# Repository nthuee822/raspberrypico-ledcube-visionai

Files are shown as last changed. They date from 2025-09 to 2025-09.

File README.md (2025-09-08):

# raspberrypico-ledcube-visionai
An application of a Raspberry Pi Pico–based 8x8x8 LED cube with Grove Vision AI v2 module

## Introduction

There are many tutorials online about how to build an 8x8x8 LED Cube, but very few showcase practical applications. During an exhibition, we came across the Grove Vision AI V2 module, which inspired us to combine the two into a unique project.

Here’s how our system works: the camera on the Grove Vision AI V2 first recognizes a hand gesture (rock, paper, or scissors). It then sends the result via I²C to the Raspberry Pi Pico 2. The Pico 2 processes the data and communicates with the LED Cube’s PCB through the SPI interface. The PCB, equipped with eight shift registers, controls the LED Cube’s X–Y plane, while an additional perfboard manages the Z-axis. We will present the hardware setup in the next section.

This project is significant for two main reasons. First, we developed a library for the Grove Vision AI V2 to transmit data to Raspberry Pi Pico , making it easier for developers to integrate and leverage its vision features. Second, we created a generalized Raspberry Pi Pico library for the 8x8x8 LED Cube, allowing developers to easily modify display patterns simply by adjusting the code.

## Getting Started

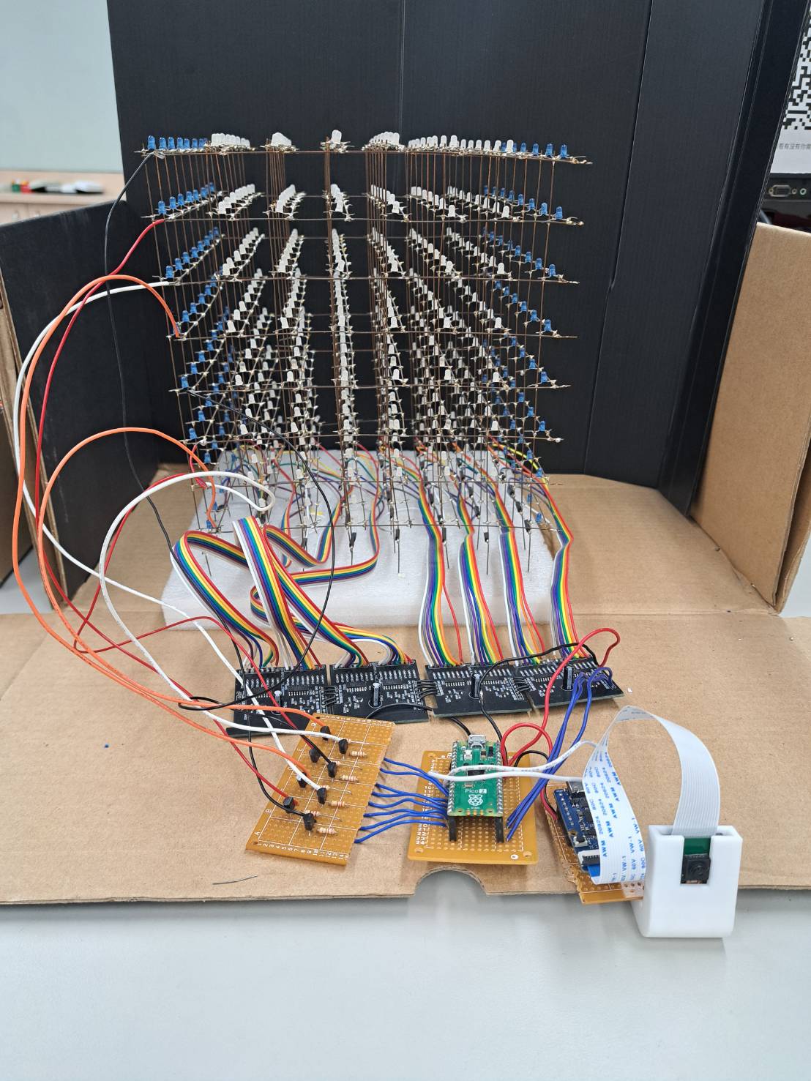
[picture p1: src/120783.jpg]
<p align="center"> <br> figure 1. </p>

### Hardware setup: Grove vision AI v2 module

We recommend using the more powerful Grove Vision AI V2 for this project. Setup instructions can be found at the official guide: https://wiki.seeedstudio.com/grove_vision_ai_v2/.

The connection between the Grove Vision AI V2, Raspberry Pi Pico 2, and the PCB with eight shift registers is shown in figure 2.

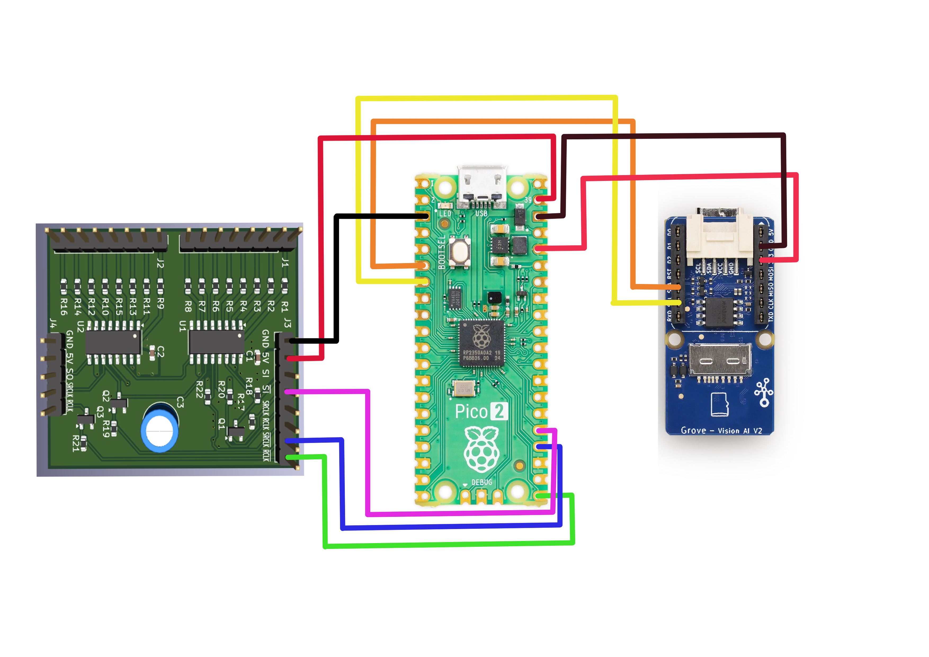
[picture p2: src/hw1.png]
<p align="center"> <br> figure 2. </p>

### Hardware setup: 8x8x8 LED Cube

The four PCBs, each with eight shift registers, are connected as shown in figure 3.

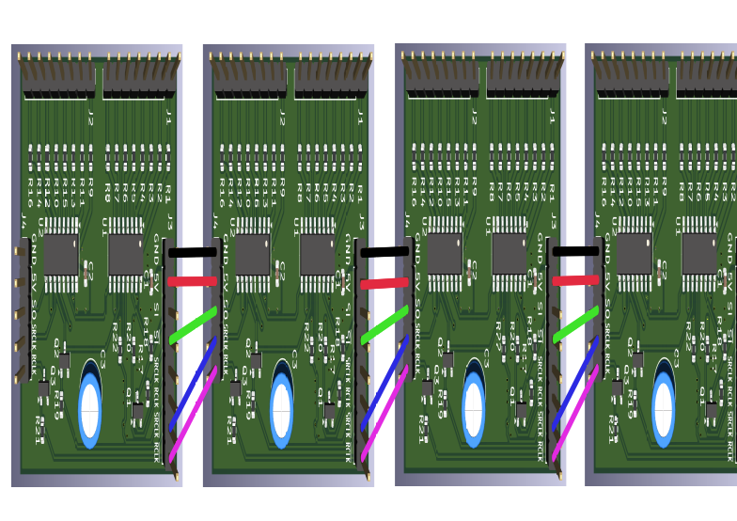
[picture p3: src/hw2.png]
<p align="center"> <br> figure 3. </p>

The perfboard manages the Z-axis. Pins 6 to 13 on the Raspberry Pi Pico 2 are connected to eight 220 Ω resistors and eight NPN transistors, as shown in figure 4.

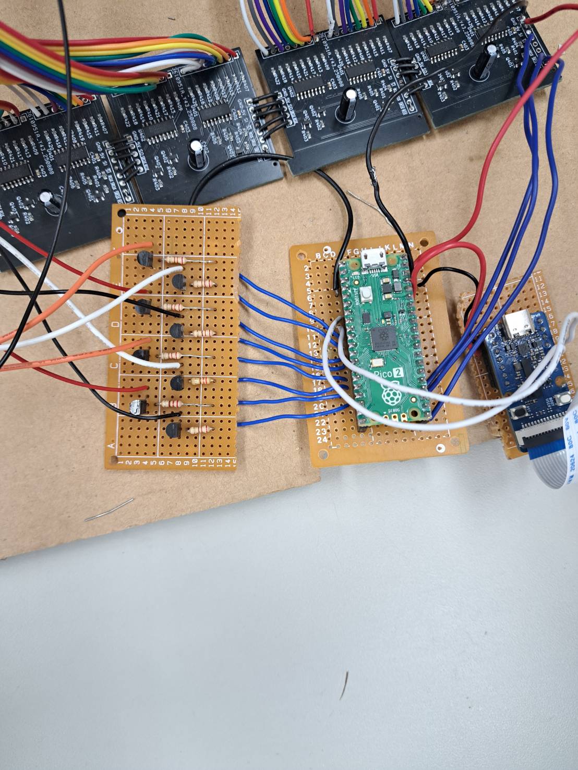
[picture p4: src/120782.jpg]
<p align="center"> <br> figure 4. </p>

## Software

### Grove vision AI v2 module

We revised the official Seeed_Arduino_SSCMA library (originally for Arduino) into an I²C interface library for the Raspberry Pi Pico.
This makes it easier to integrate the Grove Vision AI V2 with Pico-based projects.

### 8x8x8 LED Cube
We provide two versions of code for the LED Cube:

#### led_cube.c
A standalone project with several predefined special effects.
Simply run the code on the Raspberry Pi Pico, and it will light up the 8x8x8 LED Cube with built-in animations.

#### Cube_general.c
A more generalized implementation.
Developers can easily customize display effects by modifying only the matrix definition.

### Combination
Finally, we integrated everything into a rock–paper–scissors gesture recognition system.
The Grove Vision AI V2 recognizes the gesture, and the result is projected onto the 8x8x8 LED Cube.

For further details, please refer to Cube.cpp.

## Equipment Used

- [Raspberry Pi Pico](https://www.raspberrypi.com/products/raspberry-pi-pico/)
- [Grove Vision AI V2](https://wiki.seeedstudio.com/grove_vision_ai_v2/)
- [Seeed-Arduino_SSCMA Library](https://github.com/Seeed-Studio/Seeed_Arduino_SSCMA/)

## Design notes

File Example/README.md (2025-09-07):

We also created several special effects for the LED Cube in the file led_cube.c.
This version is a standalone project that does not use the AI Vision module.
Simply run the code on the Raspberry Pi Pico, and it will light up the 8x8x8 LED Cube with predefined animations.

For developers who prefer more flexibility, we provide Cube_general.c, which offers a generalized implementation.
With this code, display effects can be easily modified by changing only the matrix definition.

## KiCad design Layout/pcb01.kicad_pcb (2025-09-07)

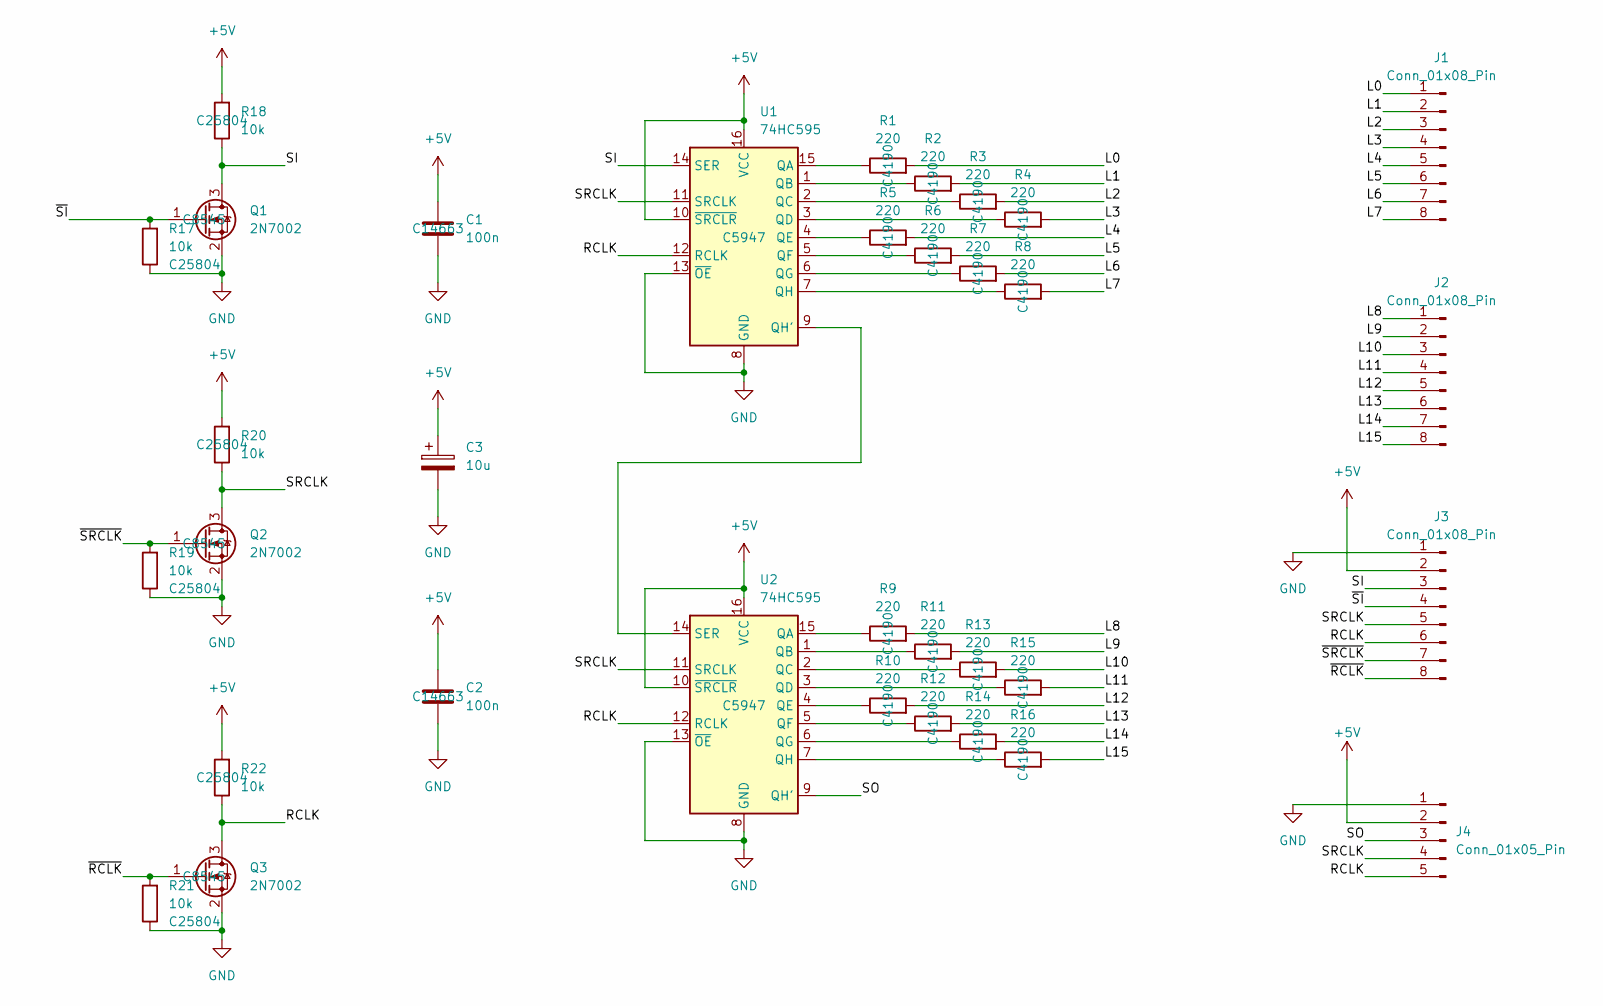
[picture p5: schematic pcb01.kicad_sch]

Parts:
C1, C2: 100n; C_0603_1608Metric; LCSC C14663
C3: 10u; C_Radial_D6.3mm_H7.0mm_P2.50mm
J1, J2, J3: Conn_01x08_Pin; PinHeader_1x08_P2.54mm_Vertical
J4: Conn_01x05_Pin; PinHeader_1x05_P2.54mm_Vertical
Q1, Q2, Q3: 2N7002; SOT-23; LCSC C8545
R1, R2, R3, R4, R5, R6, R7, R8, R9, R10, R11, R12, R13, R14, R15, R16: 220; R_0603_1608Metric; LCSC C4190
R17, R18, R19, R20, R21, R22: 10k; R_0603_1608Metric; LCSC C25804
U1, U2: 74HC595; SOIC-16_3.9x9.9mm_P1.27mm; LCSC C5947

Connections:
+5V: C1.1, C2.1, C3.1, J3.2, J4.2, R18.2, R20.2, R22.2, U1.10 (~SRCLR), U1.16 (VCC), U2.10 (~SRCLR), U2.16 (VCC)
/L0: J1.1, R1.2
/L1: J1.2, R2.2
/L2: J1.3, R3.2
/L3: J1.4, R4.2
/L4: J1.5, R5.2
/L5: J1.6, R6.2
/L6: J1.7, R7.2
/L7: J1.8, R8.2
/L8: J2.1, R9.2
/L9: J2.2, R11.2
/L10: J2.3, R13.2
/L11: J2.4, R15.2
/L12: J2.5, R10.2
/L13: J2.6, R12.2
/L14: J2.7, R14.2
/L15: J2.8, R16.2
/RCLK: J3.6, J4.5, Q3.3 (D), R22.1, U1.12 (RCLK), U2.12 (RCLK)
/SI: J3.3, Q1.3 (D), R18.1, U1.14 (SER)
/SO: J4.3, U2.9 (QH')
/SRCLK: J3.5, J4.4, Q2.3 (D), R20.1, U1.11 (SRCLK), U2.11 (SRCLK)
/~RCLK: J3.8, Q3.1 (G), R21.2
/~SI: J3.4, Q1.1 (G), R17.2
/~SRCLK: J3.7, Q2.1 (G), R19.2
GND: C1.2, C2.2, C3.2, J3.1, J4.1, Q1.2 (S), Q2.2 (S), Q3.2 (S), R17.1, R19.1, R21.1, U1.8 (GND), U1.13 (~OE), U2.8 (GND), U2.13 (~OE)
unnamed: R1.1, U1.15 (QA)
unnamed: R2.1, U1.1 (QB)
unnamed: R3.1, U1.2 (QC)
unnamed: R4.1, U1.3 (QD)
unnamed: R5.1, U1.4 (QE)
unnamed: R6.1, U1.5 (QF)
unnamed: R7.1, U1.6 (QG)
unnamed: U1.9 (QH'), U2.14 (SER)
unnamed: R8.1, U1.7 (QH)
unnamed: R9.1, U2.15 (QA)
unnamed: R11.1, U2.1 (QB)
unnamed: R13.1, U2.2 (QC)
unnamed: R15.1, U2.3 (QD)
unnamed: R10.1, U2.4 (QE)
unnamed: R12.1, U2.5 (QF)
unnamed: R14.1, U2.6 (QG)
unnamed: R16.1, U2.7 (QH)

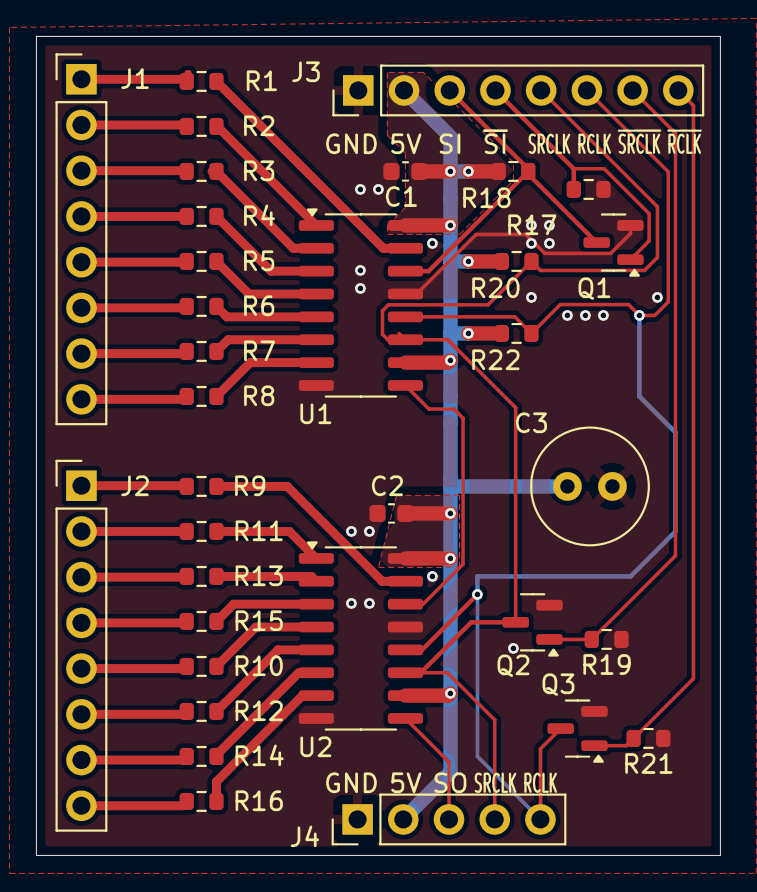
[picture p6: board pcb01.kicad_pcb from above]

Board: 2 copper layers, 38.0 x 45.5 mm, 34 parts (0 on the bottom side), 42 nets.

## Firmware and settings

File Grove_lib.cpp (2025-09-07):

#include "Grove_lib.h"

#define SPI_CS(x)                 \
    do                            \
    {                             \
        if (_cs >= 0)             \
            gpio_put(_cs, x); \
    } while (0)
 
SSCMA::SSCMA()
{
    _i2c = NULL;
    _address = I2C_ADDRESS;
    _wait_delay = 2;
    _rst = -1;
    _cs = -1;
    _sync = -1;
    tx_len = 0;
    rx_len = 0;
}
 
SSCMA::~SSCMA() {}
 
bool SSCMA::begin(i2c_inst_t *i2c, int32_t rst, uint16_t address, uint32_t wait_delay,
                   uint32_t clock)
{
    _rst = rst;
    _i2c = i2c;
    _address = address;
    _wait_delay = wait_delay;

    i2c_init(i2c, 100 * 1000);
    gpio_set_function(I2C_SDA_PIN, GPIO_FUNC_I2C);
    gpio_set_function(I2C_SCL_PIN, GPIO_FUNC_I2C);
    gpio_pull_up(I2C_SDA_PIN);
    gpio_pull_up(I2C_SCL_PIN);

    set_rx_buffer(SSCMA_MAX_RX_SIZE);
    set_tx_buffer(SSCMA_MAX_TX_SIZE);
 
    if (response != NULL) {
        cJSON_Delete(response);
    }
    response = cJSON_CreateObject();
 
    if (_rst >= 0)
    {
        gpio_init(_rst);
        gpio_set_dir(_rst, GPIO_OUT);
        gpio_put(_rst, 0);
        sleep_ms(50);
        gpio_put(_rst, 1);
        sleep_ms(500);
    }

    return ID(false) && name(false);
}

int SSCMA::write(const char *data, int length)
{
        return i2c_write(data, length);
}
 
int SSCMA::read(char *data, int length)
{
        return i2c_read(data, length);
}
 
int SSCMA::available()
{
        return i2c_available();
}
 
void SSCMA::i2c_cmd(uint8_t feature, uint8_t cmd, uint16_t len, uint8_t *data)
{
    sleep_ms(_wait_delay);
    uint8_t buf[64];
    int idx = 0;
    buf[idx++] = feature;
    buf[idx++] = cmd;
    buf[idx++] = (len >> 8) & 0xFF;
    buf[idx++] = len & 0xFF;

    if (data != nullptr) {
        memcpy(&buf[idx], data, len);
        idx += len;
    }

    // TODO checksum
    buf[idx++] = 0;
    buf[idx++] = 0;
    i2c_write_blocking(_i2c, _address, buf, idx, false);
}


int SSCMA::i2c_available()
{
    uint8_t cmd[6] = {
        FEATURE_TRANSPORT,
        FEATURE_TRANSPORT_CMD_AVAILABLE,
        0, 0,  // payload length = 0
        0, 0   // checksum
    };

    uint8_t buf[2] = {0};

    int ret1 = i2c_write_blocking(_i2c, _address, cmd, sizeof(cmd), false);
    if (ret1 < 0) {
        printf("Write failed (ret1=%d)\n", ret1);
        return -1;
    }

    sleep_ms(10);

    int ret = i2c_read_blocking(_i2c, _address, buf, 2, false);
    if (ret < 0) {
        printf("Read failed (ret=%d)\n", ret);
        return -1;
    }

    printf("Available: 0x%02X 0x%02X (%d)\n", buf[0], buf[1], (buf[0] << 8) | buf[1]);
    return (buf[0] << 8) | buf[1];
}



int SSCMA::i2c_read(char *data, int length)
{
    uint16_t packets = length / MAX_PL_LEN;
    uint8_t remain = length % MAX_PL_LEN;

    for (uint16_t i = 0; i < packets; i++) {
        sleep_ms(_wait_delay);

        uint8_t cmd[6] = {
            FEATURE_TRANSPORT, FEATURE_TRANSPORT_CMD_READ,
            (uint8_t)(MAX_PL_LEN >> 8), (uint8_t)(MAX_PL_LEN & 0xFF),
            0, 0
        };

        if (i2c_write_blocking(_i2c, _address, cmd, sizeof(cmd), false) >= 0) {
            sleep_ms(_wait_delay);
            i2c_read_blocking(_i2c, _address, (uint8_t *)(data + i * MAX_PL_LEN), MAX_PL_LEN, false);
        }
    }

    if (remain) {
        sleep_ms(_wait_delay);

        uint8_t cmd[6] = {
            FEATURE_TRANSPORT, FEATURE_TRANSPORT_CMD_READ,
            (uint8_t)(remain >> 8), (uint8_t)(remain & 0xFF),
            0, 0
        };

        if (i2c_write_blocking(_i2c, _address, cmd, sizeof(cmd), false) >= 0) {
            sleep_ms(_wait_delay);
            i2c_read_blocking(_i2c, _address, (uint8_t *)(data + packets * MAX_PL_LEN), remain, false);
        }
    }

    return length;
}
 
int SSCMA::i2c_write(const char *data, int length)
{
    uint16_t packets = length / MAX_PL_LEN;
    uint16_t remain = length % MAX_PL_LEN;

    for (uint16_t i = 0; i < packets; i++) {
        sleep_ms(_wait_delay);

        uint8_t buf[6 + MAX_PL_LEN];
        buf[0] = FEATURE_TRANSPORT;
        buf[1] = FEATURE_TRANSPORT_CMD_WRITE;
        buf[2] = (MAX_PL_LEN >> 8);
        buf[3] = (MAX_PL_LEN & 0xFF);
        memcpy(&buf[4], data + i * MAX_PL_LEN, MAX_PL_LEN);
        buf[4 + MAX_PL_LEN] = 0; // checksum
        buf[5 + MAX_PL_LEN] = 0;

        i2c_write_blocking(_i2c, _address, buf, 6 + MAX_PL_LEN, false);
    }

    if (remain) {
        sleep_ms(_wait_delay);

        uint8_t buf[6 + MAX_PL_LEN];
        buf[0] = FEATURE_TRANSPORT;
        buf[1] = FEATURE_TRANSPORT_CMD_WRITE;
        buf[2] = (remain >> 8);
        buf[3] = (remain & 0xFF);
        memcpy(&buf[4], data + packets * MAX_PL_LEN, remain);
        buf[4 + remain] = 0;
        buf[5 + remain] = 0;

        i2c_write_blocking(_i2c, _address, buf, 6 + remain, false);
    }

    return length;
}
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

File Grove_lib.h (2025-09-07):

#ifndef GROVE_LIB_H
#define GROVE_LIB_H

/***
 * Seeed_Arduino_SSCMA.h
 * Description: A drive for Seeed Grove AI Family.
 * 2022 Copyright (c) Seeed Technology Inc.  All right reserved.
 * Author: Hongtai Liu(lht856@foxmail.com)
 *
 * Copyright (C) 2020  Seeed Technology Co.,Ltd.
 *
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
 * THE SOFTWARE IS PROVIDED "AS IS", WITHOUT WARRANTY OF ANY KIND, EXPRESS OR
 * IMPLIED, INCLUDING BUT NOT LIMITED TO THE WARRANTIES OF MERCHANTABILITY,
 * FITNESS FOR A PARTICULAR PURPOSE AND NONINFRINGEMENT. IN NO EVENT SHALL THE
 * AUTHORS OR COPYRIGHT HOLDERS BE LIABLE FOR ANY CLAIM, DAMAGES OR OTHER
 * LIABILITY, WHETHER IN AN ACTION OF CONTRACT, TORT OR OTHERWISE, ARISING FROM,
 * OUT OF OR IN CONNECTION WITH THE SOFTWARE OR THE USE OR OTHER DEALINGS IN
 * THE SOFTWARE.
 */

#if defined(__AVR__)
#error "Insufficient memory: This code cannot run on any AVR platform due to limited memory."
#endif

#ifndef SSCMA_UART_BAUD
#define SSCMA_UART_BAUD 921600
#endif
#ifndef SSCMA_IIC_CLOCK
#define SSCMA_IIC_CLOCK 400000
#endif
#ifndef SSCMA_SPI_CLOCK
#define SSCMA_SPI_CLOCK 15000000
#endif
#ifndef SSCMA_MAX_RX_SIZE
#define SSCMA_MAX_RX_SIZE 16 * 1024
#endif
#ifndef SSCMA_MAX_TX_SIZE
#define SSCMA_MAX_TX_SIZE 16 * 1024
#endif

#include <stdio.h>
#include <stdint.h>
#include <string>
#include <cstring>
#include <cstdlib>
#include "pico/stdlib.h"
#include "hardware/gpio.h"
#include "pico/binary_info.h"
#include "hardware/i2c.h"

#include <vector>
#include <functional>

#include "cJSON.h"

#define I2C_PORT i2c0
#define PIN_MOSI 19
#define PIN_MISO 16
#define PIN_SCK 18  //SPI CLK
#define D0 17
#define D1 20
#define I2C_SDA_PIN 4
#define I2C_SCL_PIN 5


#define I2C_ADDRESS (0x62)

#define HEADER_LEN (uint8_t)4
#define MAX_PL_LEN (uint8_t)250
#define MAX_SPI_PL_LEN (uint16_t)4095
#define CHECKSUM_LEN (uint8_t)2

#define PACKET_SIZE (uint16_t)(HEADER_LEN + MAX_PL_LEN + CHECKSUM_LEN)

#define FEATURE_TRANSPORT 0x10
#define FEATURE_TRANSPORT_CMD_READ 0x01
#define FEATURE_TRANSPORT_CMD_WRITE 0x02
#define FEATURE_TRANSPORT_CMD_AVAILABLE 0x03
#define FEATURE_TRANSPORT_CMD_START 0x04
#define FEATURE_TRANSPORT_CMD_STOP 0x05
#define FEATURE_TRANSPORT_CMD_RESET 0x06

#define RESPONSE_PREFIX "\r{"
#define RESPONSE_SUFFIX "}\n"

#define RESPONSE_PREFIX_LEN (sizeof(RESPONSE_PREFIX) - 1)
#define RESPONSE_SUFFIX_LEN (sizeof(RESPONSE_SUFFIX) - 1)

#define CMD_PREFIX "AT+"
#define CMD_SUFFIX "\r\n"

#define CMD_TYPE_RESPONSE 0
#define CMD_TYPE_EVENT 1
#define CMD_TYPE_LOG 2

const char CMD_AT_ID[] = "ID?";
const char CMD_AT_NAME[] = "NAME?";
const char CMD_AT_VERSION[] = "VER?";
const char CMD_AT_STATS[] = "STAT";
const char CMD_AT_BREAK[] = "BREAK";
const char CMD_AT_RESET[] = "RST";
const char CMD_AT_WIFI[] = "WIFI";
const char CMD_AT_WIFI_VER[] = "WIFIVER"; // wifi version
const char CMD_AT_WIFI_STA[] = "WIFISTA"; // wifi status
const char CMD_AT_WIFI_IN4[] = "WIFIIN4";
const char CMD_AT_WIFI_IN6[] = "WIFIIN6";
const char CMD_AT_MQTTSERVER[] = "MQTTSERVER";
const char CMD_AT_MQTTPUBSUB[] = "MQTTPUBSUB";
const char CMD_AT_MQTTSERVER_STA[] = "MQTTSERVERSTA"; // mqtt status
const char CMD_AT_INVOKE[] = "INVOKE";
const char CMD_AT_SAMPLE[] = "SAMPLE";
const char CMD_AT_INFO[] = "INFO";
const char CMD_AT_TSCORE[] = "TSCORE";
const char CMD_AT_TIOU[] = "TIOU";
const char CMD_AT_ALGOS[] = "ALGOS";
const char CMD_AT_MODELS[] = "MODELS";
const char CMD_AT_MODEL[] = "MODEL";
const char CMD_AT_SENSORS[] = "SENSORS";
const char CMD_AT_ACTION[] = "ACTION";
const char CMD_AT_LED[] = "led";
const char CMD_AT_SAVE_JPEG[] = "save_jpeg()";

#define CMD_OK 0
#define CMD_AGAIN 1
#define CMD_ELOG 2
#define CMD_ETIMEDOUT 3
#define CMD_EIO 4
#define CMD_EINVAL 5
#define CMD_ENOMEM 6
#define CMD_EBUSY 7
#define CMD_ENOTSUP 8
#define CMD_EPERM 9
#define CMD_EUNKNOWN 10

const char EVENT_INVOKE[] = "INVOKE";
const char EVENT_SAMPLE[] = "SAMPLE";
const char EVENT_WIFI[] = "WIFI";
const char EVENT_MQTT[] = "MQTT";
const char EVENT_SUPERVISOR[] = "SUPERVISOR";

const char LOG_AT[] = "AT";
const char LOG_LOG[] = "LOG";

typedef std::function<void(const char *resp, size_t len)> ResponseCallback;

typedef struct
{
    uint16_t x;
    uint16_t y;
    uint16_t w;
    uint16_t h;
    uint8_t score;
    uint8_t target;
} boxes_t;

typedef struct
{
    uint8_t target;
    uint8_t score;
} classes_t;

typedef struct
{
    uint16_t x;
    uint16_t y;
    uint16_t z;
    uint8_t score;
    uint8_t target;
} point_t;

typedef struct
{
    boxes_t box;
    std::vector<point_t> points;
} keypoints_t;

typedef struct
{
    uint16_t prepocess;
    uint16_t inference;
    uint16_t postprocess;
} perf_t;

class SSCMA
{
private:
    i2c_inst_t *_i2c;
    int32_t _cs;
    int32_t _sync;
    int32_t _rst;
    uint32_t _baud;
    uint16_t _address;
    int _wait_delay;
    perf_t _perf;
    std::vector<boxes_t> _boxes;
    std::vector<classes_t> _classes;
    std::vector<point_t> _points;
    std::vector<keypoints_t> _keypoints;

    char _name[32] = {0};
    char _ID[32] = {0};

    uint32_t rx_end = 0;

    std::string _image = "";
    std::string _info = "";

    char *tx_buf; // for cmd
    uint32_t tx_len;
    char *rx_buf; // for response
    uint32_t rx_len;
    char *payload; // for json payload

    cJSON *response = nullptr;

public:
    SSCMA();
    ~SSCMA();

    bool begin(i2c_inst_t *i2c = I2C_PORT, int32_t rst = -1, uint16_t address = I2C_ADDRESS,
               uint32_t wait_delay = 2, uint32_t clock = SSCMA_IIC_CLOCK);

    int invoke(int times = 1, bool filter = 0, bool show = 0);
    int available();
    int read(char *data, int length);
    int write(const char *data, int length);

    perf_t &perf() { return _perf; }
    std::vector<boxes_t> &boxes() { return _boxes; }
    std::vector<classes_t> &classes() { return _classes; }
    std::vector<point_t> &points() { return _points; }
    std::vector<keypoints_t> &keypoints() { return _keypoints; }

    char *ID(bool cache = true);
    char *name(bool cache = true);
    std::string info(bool cache = true);

    // actions
    int clean_actions();
    int save_jpeg();

    std::string last_image() { return _image; }

    bool set_rx_buffer(uint32_t size);
    bool set_tx_buffer(uint32_t size);

private:
    int i2c_write(const char *data, int length);
    int i2c_read(char *data, int length);
    int i2c_available();
    void i2c_cmd(uint8_t feature, uint8_t cmd, uint16_t len = 0, uint8_t *data = NULL);

    int wait(int type, const char *cmd, uint32_t timeout = 1000);
    void praser_event(cJSON *root);
    void praser_log();
};

#endif
